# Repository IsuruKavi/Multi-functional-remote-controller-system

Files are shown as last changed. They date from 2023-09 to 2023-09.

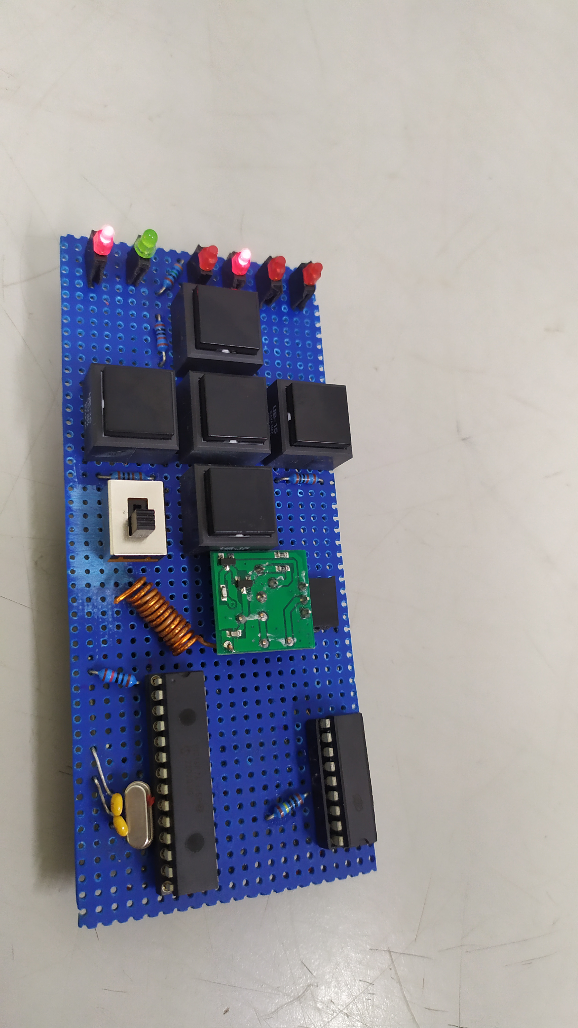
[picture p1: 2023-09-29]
Project/Video and photos/Remote_1.jpg

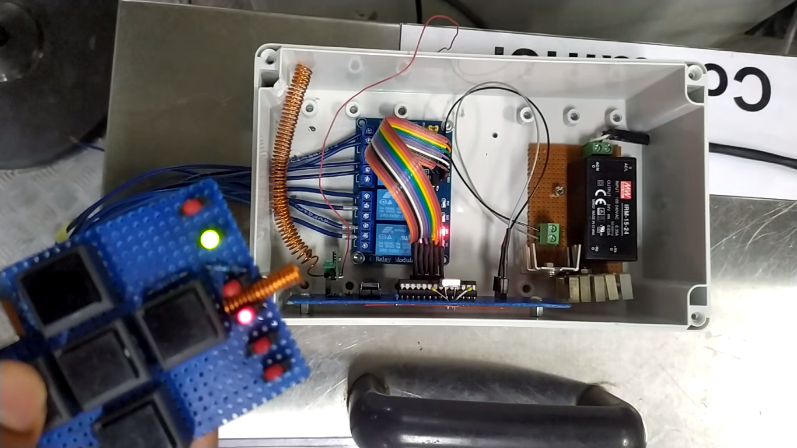
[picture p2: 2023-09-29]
Project/Video and photos/Transmitter and Receiver ends_2.png

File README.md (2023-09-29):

🚀 Successfully Designed a Remote Controller System for Wave Soldering Machine 🛠️
During my internship , I had the opportunity to work on an innovative project aimed at enhancing the safety and convenience of wave soldering machine operations. The core objective was to remotely control the hot solder bath, eliminating the need for operators to be in close proximity to the potentially dangerous liquid solder.

**Key Features**:
- I designed and implemented a user-friendly interface with four push buttons (Up, Down, In, Out) to facilitate machine operations.
- Normal operation required a 2-3 minute continuous button press, but I engineered a solution allowing operators to initiate actions with a single button press and stop the operation by pressing again.

**Two Operating Modes**:
- **Manual Mode (Green Light)**: The system defaults to this mode at startup. Operators must press and hold buttons to execute operations.
- **Auto Mode (Red Light)**: In this mode, a single button press triggers and controls the operation. Press "Out" to start, and it can be stopped by pressing "In" or "Out." Additionally, the system includes a safety feature: the relays will automatically turn off after 2.5 minutes, ensuring that even if the operator doesn't manually turn off the operation, safety is maintained.

**Seamless Mode Switching**:
- Users can effortlessly switch between modes by pressing the middle button.

**Technology Stack**:
- I harnessed RF communication with RF modules, encoders, and decoders.
- The project's core is the PIC16F76 microcontroller, enabling precise control and reliable operation.

**Code Implementation**:
-I meticulously crafted robust code for both the transmitter and receiver sides to guarantee error-free signal transmission and reception.
-A critical focus was to ensure the system could maintain control and data integrity during signal interruptions, preventing risky conditions during operations.

**PCB Design and Development**:
- Initially, I assembled the system using a vero board.
- Subsequently, I ventured into PCB design. I'll be sharing photos of the vero board for the transmitter and receiver shortly.

#####_Code,schematic and some photos have been uploaded_#####

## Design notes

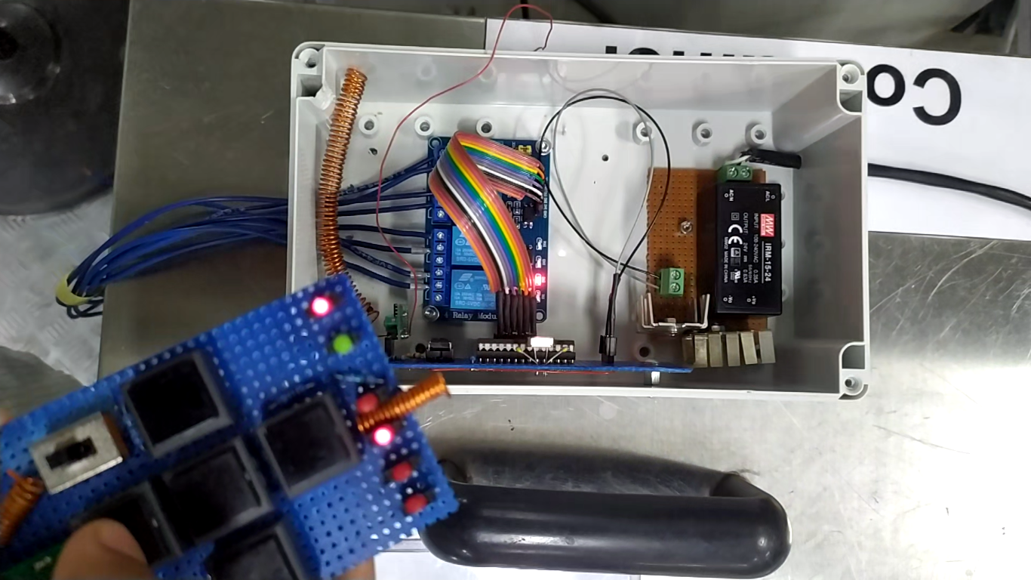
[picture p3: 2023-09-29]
Project/Video and photos/Transmitter and Receiver ends_1.png

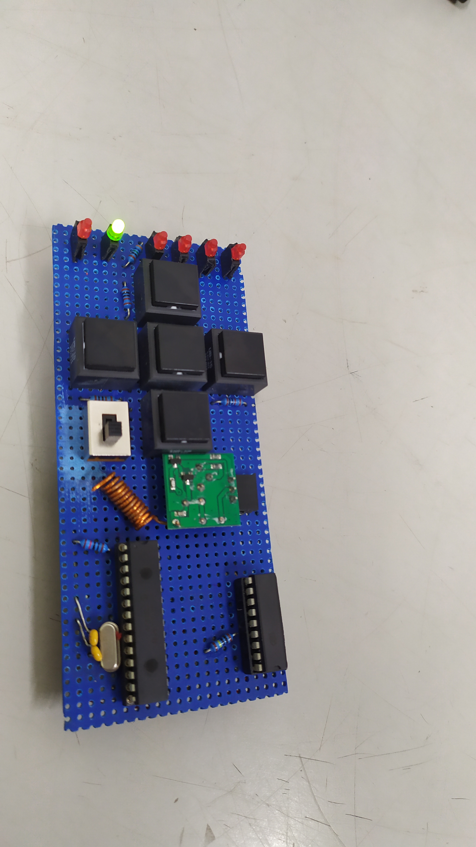
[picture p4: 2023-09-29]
Project/Video and photos/Remote_2.jpg

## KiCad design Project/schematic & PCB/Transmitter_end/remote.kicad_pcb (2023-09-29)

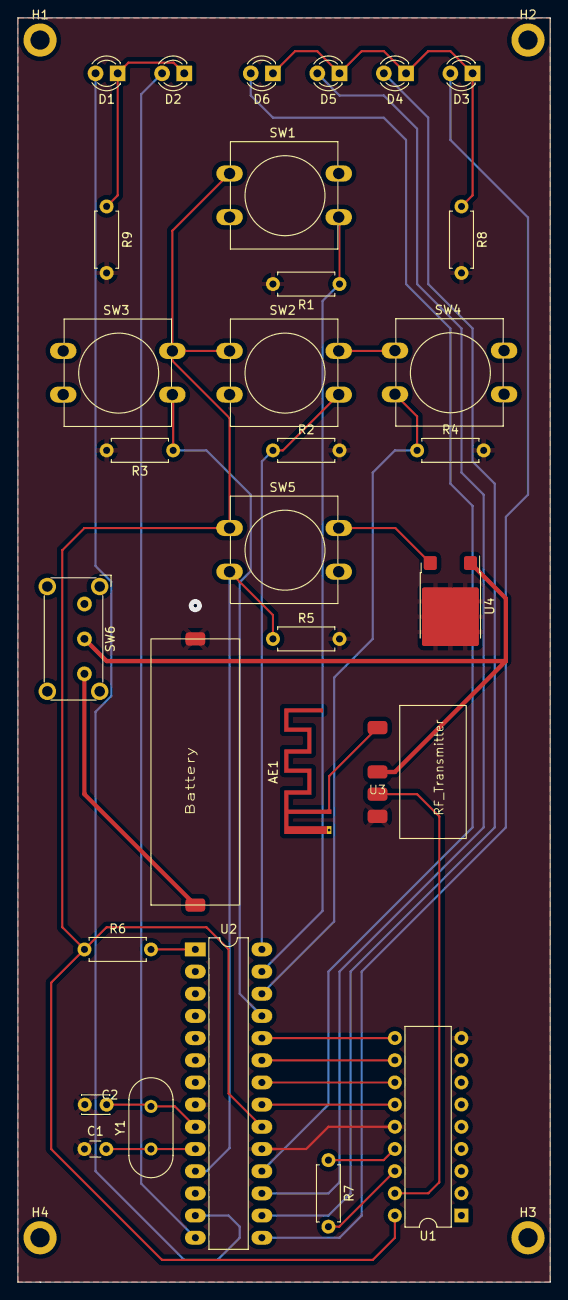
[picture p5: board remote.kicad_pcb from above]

Board: 2 copper layers, 61.0 x 144.8 mm, 34 parts (0 on the bottom side), 28 nets.

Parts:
AE1: Antenna; Texas_SWRA117D_2.4GHz_Right
BT1: Battery_Cell; battery
C1: C; C_Disc_D3.0mm_W1.6mm_P2.50mm
C2: C; C_Disc_D3.0mm_W2.0mm_P2.50mm
D1, D2, D3, D4, D5, D6: LED; LED_D3.0mm
H1, H2, H3, H4: MountingHole; MountingHole_2.2mm_M2_DIN965_Pad
R1, R2, R3, R4, R5, R6, R7, R8, R9: R; R_Axial_DIN0207_L6.3mm_D2.5mm_P7.62mm_Horizontal
SW1, SW2, SW3, SW4, SW5: SW_Push; SW_PUSH-12mm
SW6: SW_DIP_x01; SW_E-Switch_EG1224_SPDT_Angled
U1: HT12E; DIP-18_W7.62mm
U2: PIC16F76-ISP; DIP-28_W7.62mm_LongPads
U3: rf_tr
U4: L7805; ATPAK-2
Y1: Crystal; Crystal_HC49-4H_Vertical

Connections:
+5V: R6.1, SW1.1, SW2.1, SW3.1, SW4.1, SW5.1, U1.18 (VDD), U2.20 (VDD), U4.3 (OUT)
+12V: BT1.1 (+), SW6.1
GND: BT1.2 (-), C1.1, C2.1, R1.2, R2.2, R3.2, R4.2, R5.2, R8.2, R9.2, U1.9 (VSS), U1.14 (~TE), U2.8 (VSS), U2.19 (VSS), U3.3 (GND), U4.2 (GND)
unnamed: AE1.1 (A), U3.4 (Antenna)
unnamed: D1.2 (A), U2.13 (RC2/CCP1)
unnamed: D1.1 (K), D2.1 (K), R9.1
unnamed: D2.2 (A), U2.14 (RC3/SCK/SCL)
unnamed: D3.2 (A), U2.15 (RC4/SDI/SDA)
unnamed: D3.1 (K), D4.1 (K), D5.1 (K), D6.1 (K), R8.1
unnamed: D4.2 (A), U2.16 (RC5/SDO)
unnamed: D5.2 (A), U2.17 (RC6/TX/CK)
unnamed: D6.2 (A), U2.18 (RC7/RX/DT)
unnamed: U1.10 (AD8), U2.24 (PGM/RB3)
unnamed: U1.11 (AD9), U2.23 (RB2)
unnamed: U1.12 (AD10), U2.22 (RB1)
unnamed: U1.13 (AD11), U2.21 (INT/RB0)
unnamed: U1.17 (DOUT), U3.2 (Data)
unnamed: R7.2, U1.16 (OSC1)
unnamed: R7.1, U1.15 (OSC2)
unnamed: C2.2, U2.9 (OSC1/CLKIN), Y1.2
unnamed: C1.2, U2.10 (OSC2/CLKOUT), Y1.1
unnamed: R1.1, SW1.2, U2.27 (PGC/RB6)
unnamed: R2.1, SW2.2, U2.28 (PGD/RB7)
unnamed: R3.1, SW3.2, U2.25 (RB4)
unnamed: R4.1, SW4.2, U2.26 (RB5)
unnamed: R5.1, SW5.2, U2.11 (RC0/T10S0/T1CKI)
unnamed: R6.2, U2.1 (~MCLR/Vpp)
unnamed: SW6.2, U3.1 (Vcc), U4.1 (IN)

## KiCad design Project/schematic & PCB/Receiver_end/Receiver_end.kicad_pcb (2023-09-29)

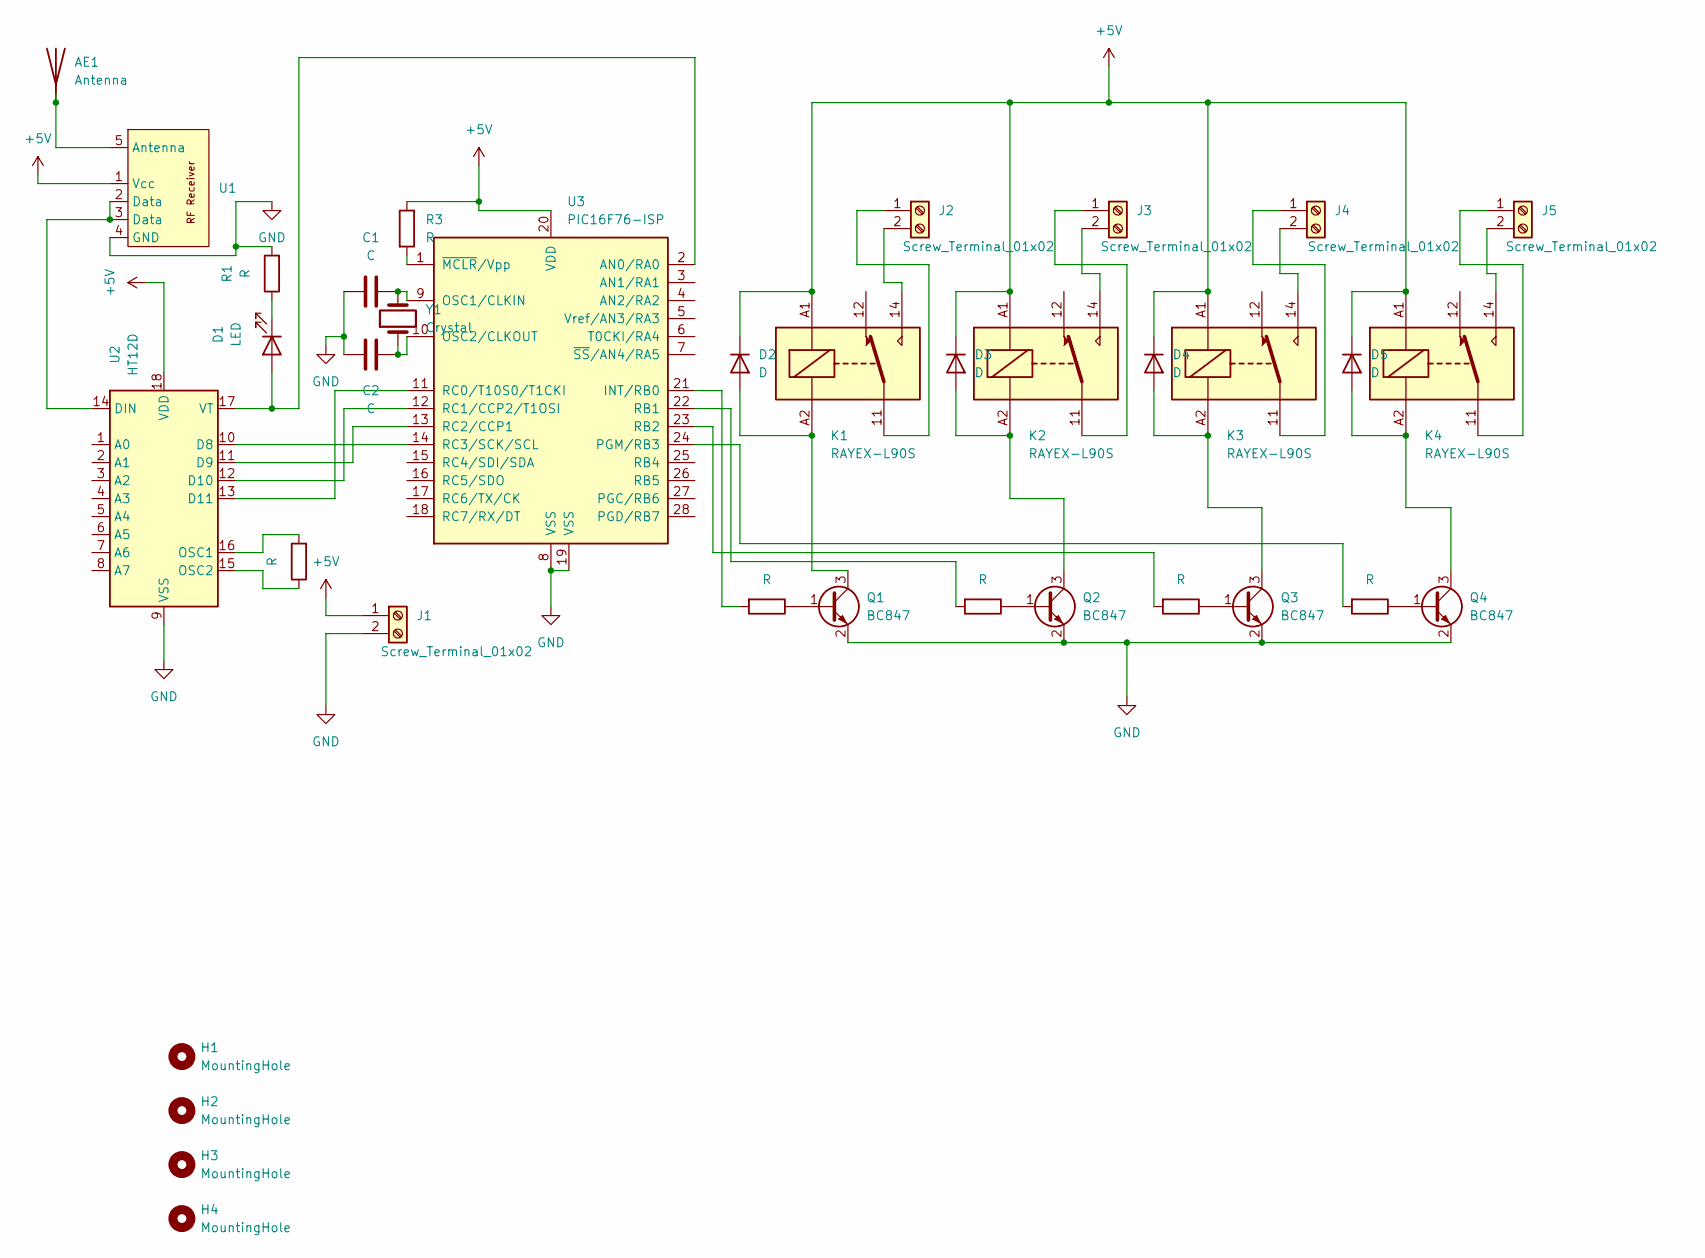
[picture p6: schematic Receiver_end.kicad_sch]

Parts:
AE1: Antenna; Texas_SWRA117D_2.4GHz_Right
C1, C2: C; C_Disc_D3.4mm_W2.1mm_P2.50mm
D1: LED; LED_D3.0mm
D2, D3, D4, D5: D; D_TUMD2
H1, H2, H3, H4: MountingHole; MountingHole_2.2mm_M2_DIN965_Pad
J1, J2, J3, J4, J5: Screw_Terminal_01x02; TerminalBlock_Phoenix_MKDS-1,5-2_1x02_P5.00mm_Horizontal
K1, K2, K3, K4: RAYEX-L90S; Relay_1-Form-C_Schrack-RYII_RM3.2mm
Q1, Q2, Q3, Q4: BC847; SOT-23
R1, R2, R3: R; R_Axial_DIN0207_L6.3mm_D2.5mm_P7.62mm_Horizontal
R4, R5, R6, R7: R; R_0603_1608Metric
U1: receiver footprint
U2: HT12D; DIP-18_W7.62mm_LongPads
U3: PIC16F76-ISP; DIP-28_W7.62mm
Y1: Crystal; Crystal_HC49-4H_Vertical

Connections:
+5V: D2.1 (K), D3.1 (K), D4.1 (K), D5.1 (K), J1.1, K1.A1, K2.A1, K3.A1, K4.A1, R3.1, U1.1 (Vcc), U2.18 (VDD), U3.20 (VDD)
GND: C1.1, C2.1, J1.2, Q1.2 (E), Q2.2 (E), Q3.2 (E), Q4.2 (E), R1.2, U1.4 (GND), U2.9 (VSS), U3.8 (VSS), U3.19 (VSS)
unnamed: AE1.1 (A), U1.5 (Antenna)
unnamed: D1.2 (A), U2.17 (VT), U3.2 (AN0/RA0)
unnamed: D1.1 (K), R1.1
unnamed: D2.2 (A), K1.A2, Q1.3 (C)
unnamed: D3.2 (A), K2.A2, Q2.3 (C)
unnamed: D4.2 (A), K3.A2, Q3.3 (C)
unnamed: D5.2 (A), K4.A2, Q4.3 (C)
unnamed: J2.1, K1.11
unnamed: J2.2, K1.14
unnamed: J3.1, K2.11
unnamed: J3.2, K2.14
unnamed: J4.1, K3.11
unnamed: J4.2, K3.14
unnamed: J5.1, K4.11
unnamed: J5.2, K4.14
unnamed: Q1.1 (B), R4.1
unnamed: Q2.1 (B), R5.1
unnamed: Q3.1 (B), R6.1
unnamed: Q4.1 (B), R7.1
unnamed: U2.10 (D8), U3.14 (RC3/SCK/SCL)
unnamed: U2.11 (D9), U3.13 (RC2/CCP1)
unnamed: U2.12 (D10), U3.12 (RC1/CCP2/T1OSI)
unnamed: U2.13 (D11), U3.11 (RC0/T10S0/T1CKI)
unnamed: U1.2 (Data), U1.3 (Data), U2.14 (DIN)
unnamed: R2.2, U2.16 (OSC1)
unnamed: R2.1, U2.15 (OSC2)
unnamed: R4.2, U3.21 (INT/RB0)
unnamed: C1.2, U3.9 (OSC1/CLKIN), Y1.2
unnamed: C2.2, U3.10 (OSC2/CLKOUT), Y1.1
unnamed: R7.2, U3.24 (PGM/RB3)
unnamed: R5.2, U3.22 (RB1)
unnamed: R6.2, U3.23 (RB2)
unnamed: R3.2, U3.1 (~MCLR/Vpp)

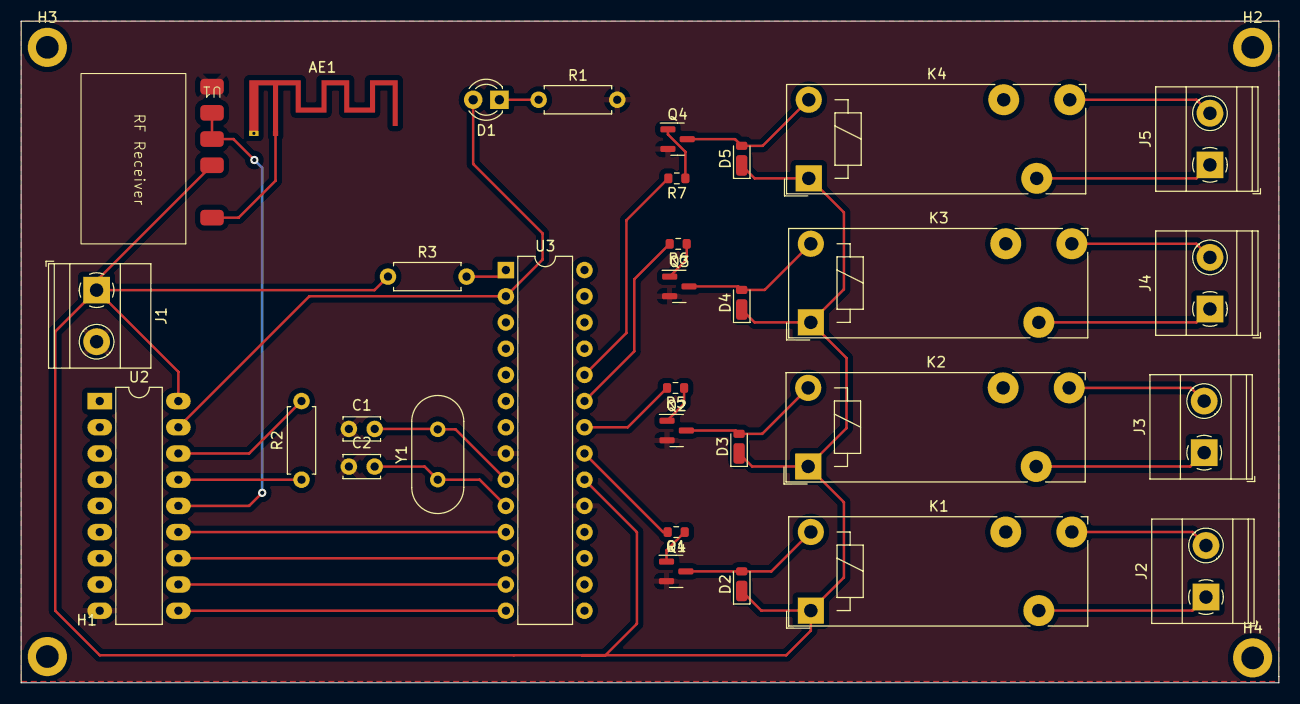
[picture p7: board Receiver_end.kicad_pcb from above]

Board: 2 copper layers, 121.9 x 64.1 mm, 36 parts (0 on the bottom side), 35 nets.

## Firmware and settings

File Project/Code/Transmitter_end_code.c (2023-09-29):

// PIC16F76 Configuration Bit Settings
// 'C' source line config statements
// CONFIG
#pragma config FOSC = HS        // Oscillator Selection bits (HS oscillator)
#pragma config WDTE = OFF       // Watchdog Timer Enable bit (WDT disabled)
#pragma config PWRTE = OFF      // Power-up Timer Enable bit (PWRT disabled)
#pragma config CP = OFF         // FLASH Program Memory Code Protection bit (Code protection off)
#pragma config BOREN = ON       // Brown-out Reset Enable bit (BOR enabled)

// #pragma config statements should precede project file includes.
// Use project enums instead of #define for ON and OFF.

#define _XTAL_FREQ 16000000
#include <xc.h>
//OUTPUTS
#define LED1        PORTCbits.RC2
#define LED2        PORTCbits.RC3
#define Out_relay   PORTBbits.RB2
#define In_relay    PORTBbits.RB3
#define Down_relay  PORTBbits.RB1
#define Up_relay    PORTBbits.RB0
#define LED_OUT      PORTCbits.RC6
#define LED_IN       PORTCbits.RC7
#define LED_DOWN      PORTCbits.RC5
#define LED_UP        PORTCbits.RC4

//INPUTS

#define Pb PORTBbits.RB6
#define Out_button PORTBbits.RB7
#define In_button PORTBbits.RB4
#define Down_button PORTBbits.RB5
#define Up_button PORTCbits.RC0

void main(void) {
    // Outputs
    TRISBbits.TRISB0 = 0;
    TRISBbits.TRISB1 = 0;
    TRISBbits.TRISB2 = 0;
    TRISBbits.TRISB3 = 0;
    TRISCbits.TRISC2 = 0;
    TRISCbits.TRISC3 = 0;
    TRISCbits.TRISC4 = 0;
    TRISCbits.TRISC5 = 0;
    TRISCbits.TRISC7 = 0;
    TRISCbits.TRISC6 = 0;

    // Inputs
    TRISCbits.TRISC0 = 1;
    TRISBbits.TRISB4 = 1;
    TRISBbits.TRISB5 = 1;
    TRISBbits.TRISB6 = 1;
    TRISBbits.TRISB7 = 1;


    //####Button_state(Bs)
    int Bs0 = 0;
    int Bs1=0;
    int Bs2=0;
    int Bs3=0;
    int Bs4=0;
    int Mode=0;
    int Val=0;
    LED1=1;
    LED2=0;
    In_relay=1;
    Out_relay=1;
    Up_relay=1;
    Down_relay=1;
      
    while (1) { 
        //code for changing the mode pressing the middle push botton(pb)
        if ( Pb == 1 && Bs0==0 ) {
            __delay_ms(50);
            
            Mode=1;
            LED1=0;
            LED2=1;
                       
            Bs1=0;
            Bs2=0;
            Bs3=0;
            Bs4=0;
            Val=1;
            
            if( Pb==0){
                Bs0=1;
                                                      
            }}
        else if(Pb==1 && Bs0==1){
            __delay_ms(50);
            Mode=0;
            LED1=1;
            LED2=0;
            Val=0;
            
            if (Pb==0){
                Bs0=0;
                
                
            }
            }
 
//        code for Manual mode
        if(Mode==0 && Val==0){
           
            if(Out_button==1){
                if(In_relay==0 && Up_relay==0 && Down_relay==0){
                    Out_relay=1;
//                    LED_OUT=1;
//                   LED_IN=0;
                }
                    
            }else{
                Out_relay=0;
//                LED_OUT=0;
            }
            if(In_button==1){
                if(Out_relay==0 && Up_relay==0 && Down_relay==0){
                    In_relay=1;
//                    LED_OUT=0;
//                    LED_IN=1;
                }
                
            }else{
                In_relay=0;
//            LED_IN=0;
            }
               
            
            if(Down_button==1){
                if(Up_relay==0 && In_relay==0 && Out_relay==0){
                Down_relay=1;
//                LED_DOWN=1;
//                LED_UP=0;
                }
            }else{
                Down_relay=0;
//                LED_DOWN=0;
            }
            if(Up_button==1){
                if(Down_relay==0 && In_relay==0 && Out_relay==0 ){
                Up_relay=1;
//                LED_DOWN=0;
//                LED_UP=1;
                }
            }else{
                Up_relay=0;
//                LED_UP=0;
            }
            
            
        }
//        code for Auto Mode
        else {
            //code for automatically turn off the relay  after 3min once operation is started.
            if(In_relay==1){
                
                
                for(int t=0; t<=3600; t++){
                   
                    
                    if(In_button==1 || Out_button==1 || Pb==1){
                        break;
                    }
                    else if(t==3600){
                        In_relay=0;
                        Bs3=0;
                    }
                    __delay_ms(50);
                }
                
            }
            if(Out_relay==1){
                
                for(int t=0; t<=3600; t++){
                   
                    
                    if(In_button==1 || Out_button==1|| Pb==1){
                        break;
                    }
                    else if(t==3600){
                        Out_relay=0;
                        Bs4=0;
                        
                    }
                    __delay_ms(50);
                }
                
            }//code for automatically turn off the relay  after 100 sec once operation is started.
            if(Up_relay==1){
                
                
                for(int t=0; t<=2000; t++){
                   
                    
                    if(Up_button==1 || Down_button==1 || Pb==1){
                        break;
                    }
                    else if(t==2000){
                        Up_relay=0;
                        Bs1=0;
                    }
                    __delay_ms(50);
                }
                
            }
            if(Down_relay==1){
                
                
                for(int t=0; t<=2000; t++){
                   
                    
                    if(Up_button==1 || Down_button==1 || Pb==1){
                        break;
                    }
                    else if(t==2000){
                        Down_relay=0;
                        Bs2=0;
                    }
                    __delay_ms(50);
                }
                
            }
            
            
////            
            
//################################Down_button
            if(Down_button==1 && Bs1==0 && In_relay==0 && Out_relay==0 && Pb==0){
                __delay_ms(50);
                
                if(Up_relay==1){
                    Up_relay=0;
                    Bs2=0;
                    Bs1=1;
                    
                }else{
                Down_relay=1;
                if(Down_button==0){
                    
                    Bs1=1;
                         
                }}}
            else if(Down_button==1 && Bs1==1){
                __delay_ms(50);
                Down_relay=0;
                if(Down_button==0){
                    Bs1=0;
                }
            }
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

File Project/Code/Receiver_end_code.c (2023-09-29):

/// PIC16F76 Configuration Bit Settings
// 'C' source line config statements
// CONFIG
#pragma config FOSC = HS        // Oscillator Selection bits (HS oscillator)
#pragma config WDTE = OFF       // Watchdog Timer Enable bit (WDT disabled)
#pragma config PWRTE = OFF      // Power-up Timer Enable bit (PWRT disabled)
#pragma config CP = OFF         // FLASH Program Memory Code Protection bit (Code protection off)
#pragma config BOREN = ON       // Brown-out Reset Enable bit (BOR enabled)

// #pragma config statements should precede project file includes.
// Use project enums instead of #define for ON and OFF.

#define _XTAL_FREQ 16000000
#include <xc.h>
//OUTPUTS

#define Out_relay   PORTBbits.RB3
#define In_relay    PORTBbits.RB2
#define Down_relay  PORTBbits.RB1
#define Up_relay    PORTBbits.RB0

//INPUTS

#define Transmission_enable PORTAbits.RA0
#define Out_button PORTCbits.RC0
#define In_button PORTCbits.RC1
#define Down_button PORTCbits.RC2
#define Up_button PORTCbits.RC3

void main(void) {
    // Outputs
    TRISBbits.TRISB0 = 0;
    TRISBbits.TRISB1 = 0;
    TRISBbits.TRISB2 = 0;
    TRISBbits.TRISB3= 0;
    

    // Inputs
    TRISCbits.TRISC0 = 1;
    TRISCbits.TRISC1 = 1;
    TRISCbits.TRISC2 = 1;
    TRISCbits.TRISC3 = 1;
    TRISAbits.TRISA0 = 1;
    
    In_relay=1;
    Out_relay=1;
    Up_relay=1;
    Down_relay=1; 
    __delay_ms(100);

    while (1) {
        //code for turning of relays when signal isn't received for 400ms 
        if(Transmission_enable==0 ){
            for(int t=0; t<=8; t++){
                    __delay_ms(50);
                    if(Transmission_enable==1){
                        break;
                    }
                    else if(t==8){
                        Up_relay=1;
                        Down_relay=1;
                        In_relay=1;
                        Out_relay=1;
                         }
                    
                }
        }//code to operate the relays.
        else{
         if(Up_button==1 && Down_button==0 && In_button==0 && Out_button==0){
           
            Up_relay=0;
                
        }
        if(Up_button==0){
            Up_relay=1;
            
        }
        if(Down_button==1 && Up_button==0 && In_button==0 && Out_button==0){
            
            Down_relay=0;
                
        }if(Down_button==0){
            Down_relay=1;
        }
        
        if(In_button==1 && Down_button==0 && Up_button==0 && Out_button==0){
           
            In_relay=0;
           
        }if(In_button==0){
            In_relay=1;
        
        }
        if(Out_button==1 &&  Down_button==0 && In_button==0 && Up_button==0){
            
            Out_relay=0;
            
        }if(Out_button==0){
            Out_relay=1;
        }
        
        }
        
    } }
